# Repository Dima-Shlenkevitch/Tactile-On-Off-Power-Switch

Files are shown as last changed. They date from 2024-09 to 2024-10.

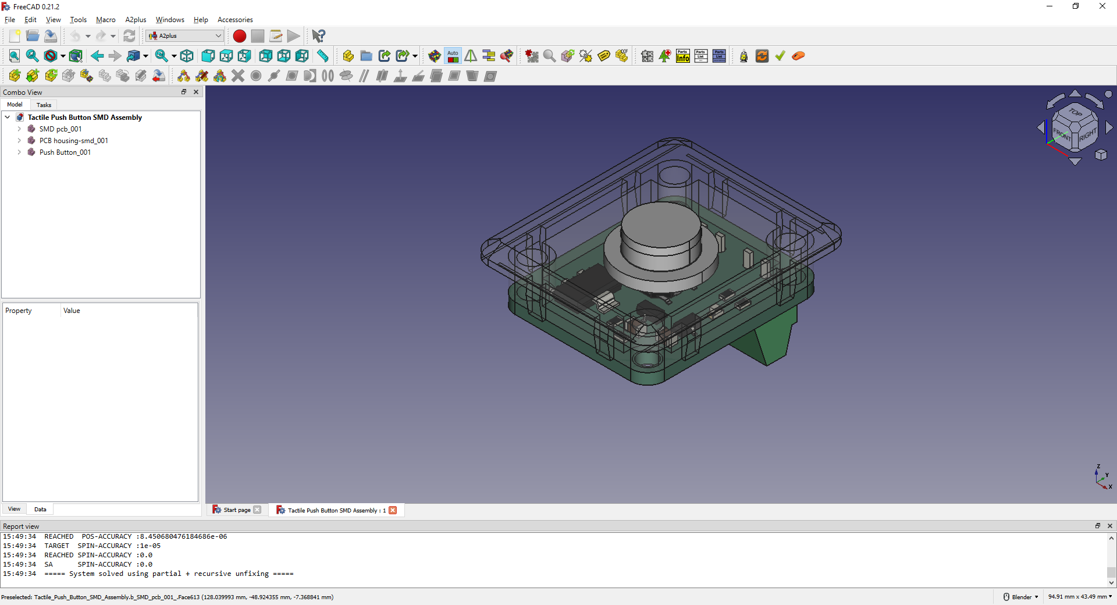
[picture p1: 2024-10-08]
Project Documentation/Step 2 - Design Phase/FreeCAD design - SMD.png

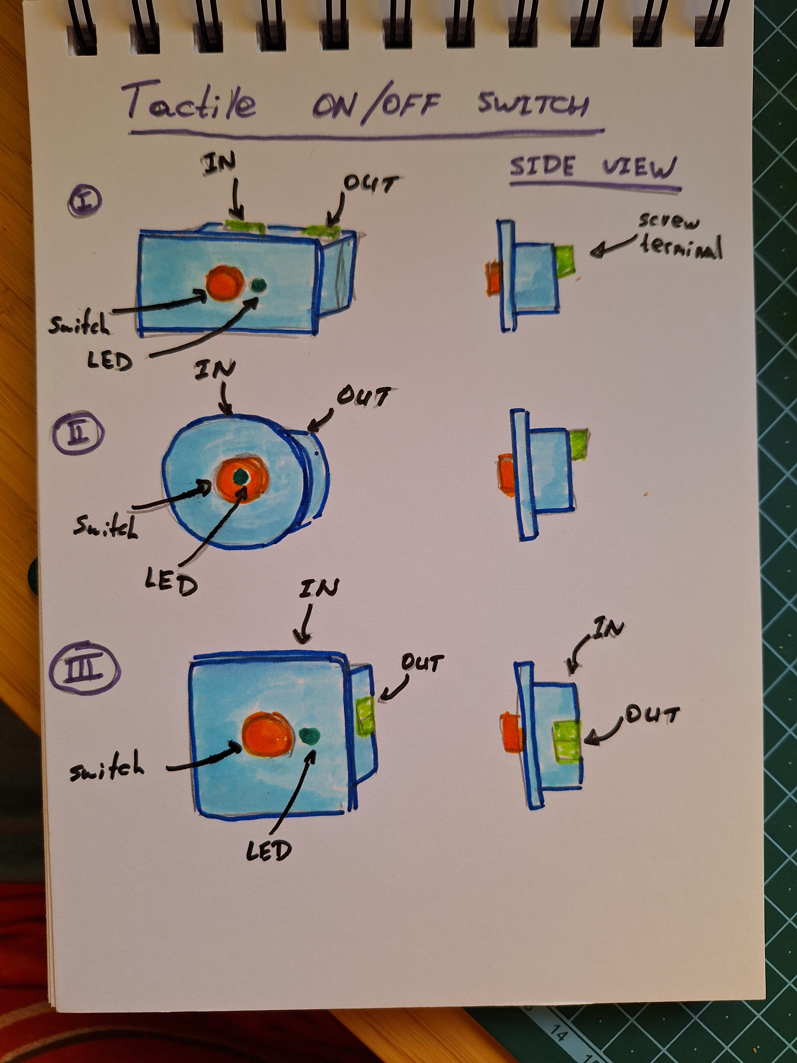
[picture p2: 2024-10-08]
Project Documentation/Step 1 - Conceptual Design/1. Hand Sketch/Concepts.jpg

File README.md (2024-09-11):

# Tactile ON / OFF Power Switch

## Project Overview
This project focuses on replacing a mechanical switch with a tactile push button and a latch circuit.

The project was inspired by an excellent video from Great Scott:
https://www.youtube.com/watch?v=y1ROEogHF7A

The main circuit remains similar to the reference design.

## Key features of this design include:
* Small footprint
* SMD components
* Mechanical enclosure for panel installation

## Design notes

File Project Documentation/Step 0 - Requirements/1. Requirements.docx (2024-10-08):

Requirements

Date: 1/9/24

Project Name: Tactile On/Off Switch Button

Responsible: D. Shlenkevitch

What the prototype should do?

The prototype replaces the on/Off mechanical switch with tactile button.

What are the must have features?

- The dimensions should be as small as possible
- The voltage input/output should be 0-12V
- The current should be up to 2A
- Screw terminals for input and output
- LED as visual indicator for power
- Mounting from the outer part of the panel

Nice to have features

- Ability to add different type of tactile switches
- Ability to mount from inner part of the panel

What are the limitations?

- Dimensions: Below 20 x 20 mm
- Price: Low price is needed, for mass production the BOM < 1$
- Specific components: N/A

Is any regulation compliance required?

- N/A

Are there any other requirements?

- N/A

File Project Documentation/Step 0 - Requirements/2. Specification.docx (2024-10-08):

Specification

Date: 1/9/24

Project Name: Tactile On/Off Switch Button

Responsible: D. Shlenkevitch

Electrical:

Input/Output Voltage: 0 – 12 V

Current: < 2 A

Input/Output: Screw Terminal

Power available indicator: Green LED

Mechanical:

Height: < 20 mm

Length: < 20 mm

Width: < 40 mm (Flexible)

Mounting side: panel outer side

Optional: PCB with mounting holes for mounting on inner side

Software:

N/A

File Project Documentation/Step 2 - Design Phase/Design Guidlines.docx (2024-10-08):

Moto: Don’t try to make the perfect prototype / product!

It is not possible! Nothing is perfect!

- Start project
- Init git
- Init github
- Capture main schematics
- Choose the components that you want

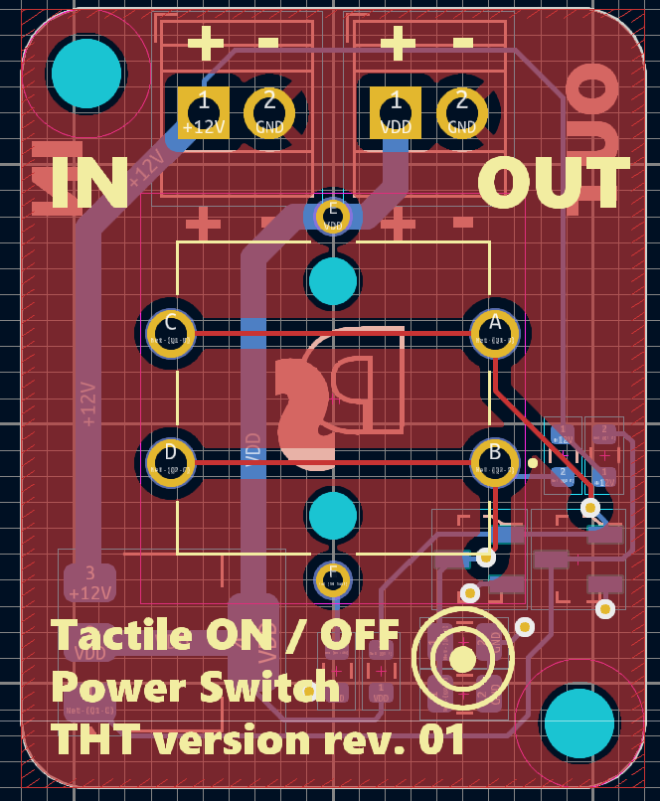
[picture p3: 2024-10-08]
Project Documentation/Step 2 - Design Phase/Electrical Design/Layout.PNG

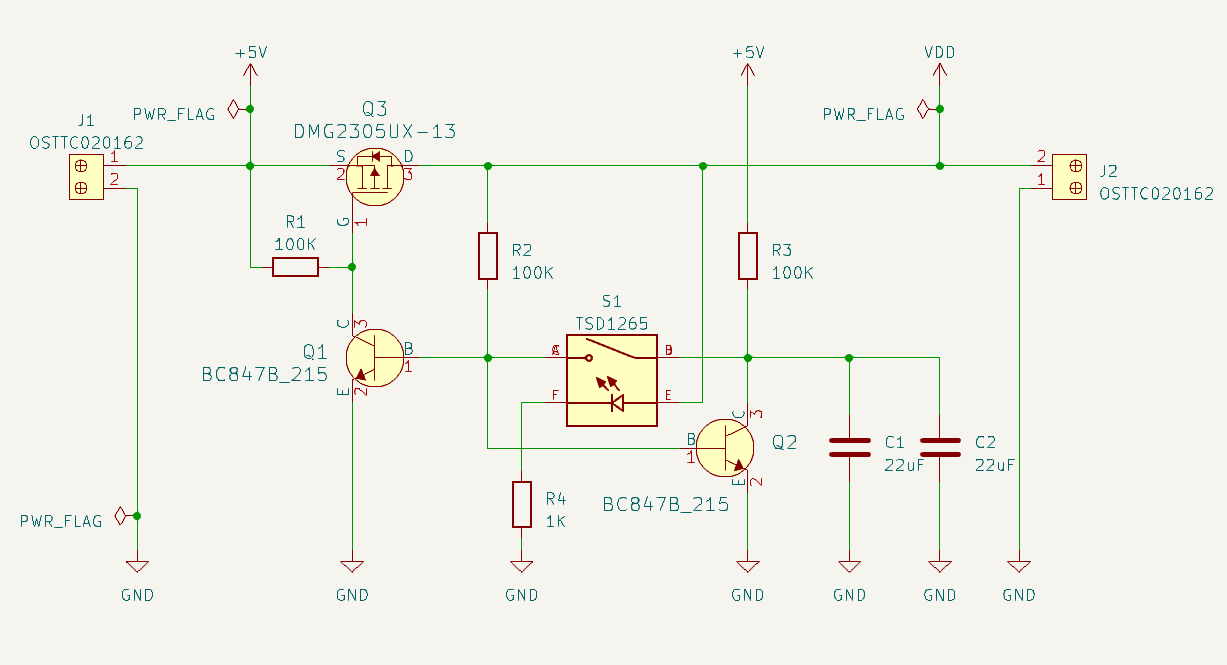
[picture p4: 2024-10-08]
Project Documentation/Step 2 - Design Phase/Electrical Design/Capture Initial Design.PNG

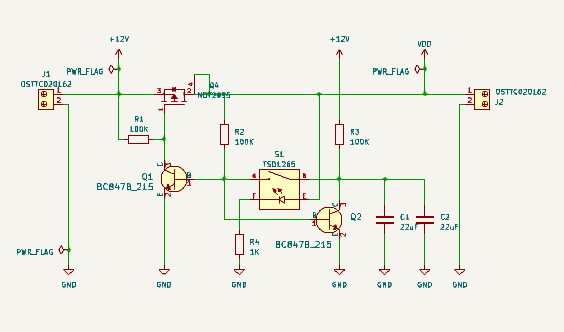
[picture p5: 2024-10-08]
Project Documentation/Step 2 - Design Phase/Electrical Design/Schematics.PNG

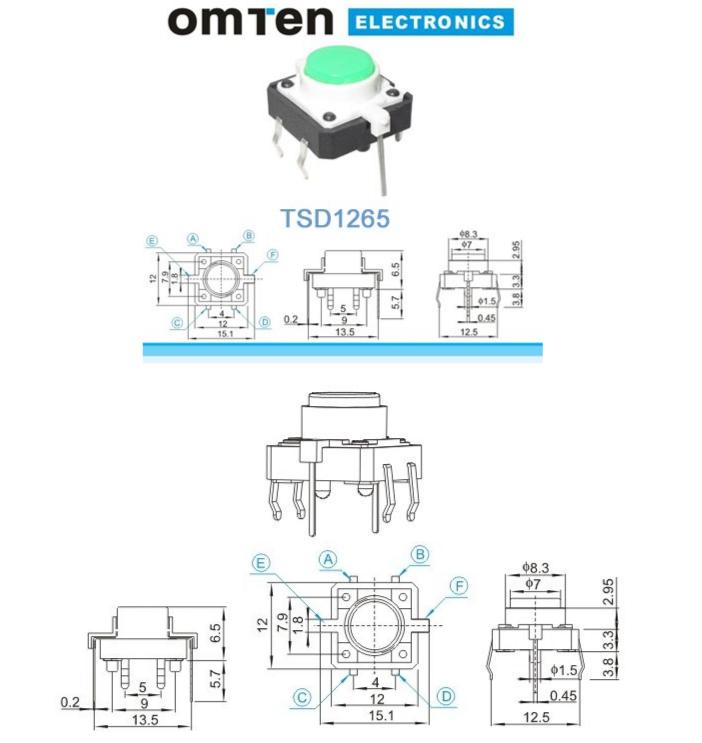
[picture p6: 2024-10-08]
Project Documentation/Step 2 - Design Phase/Electrical Design/Documents/push button spec 2.jpg

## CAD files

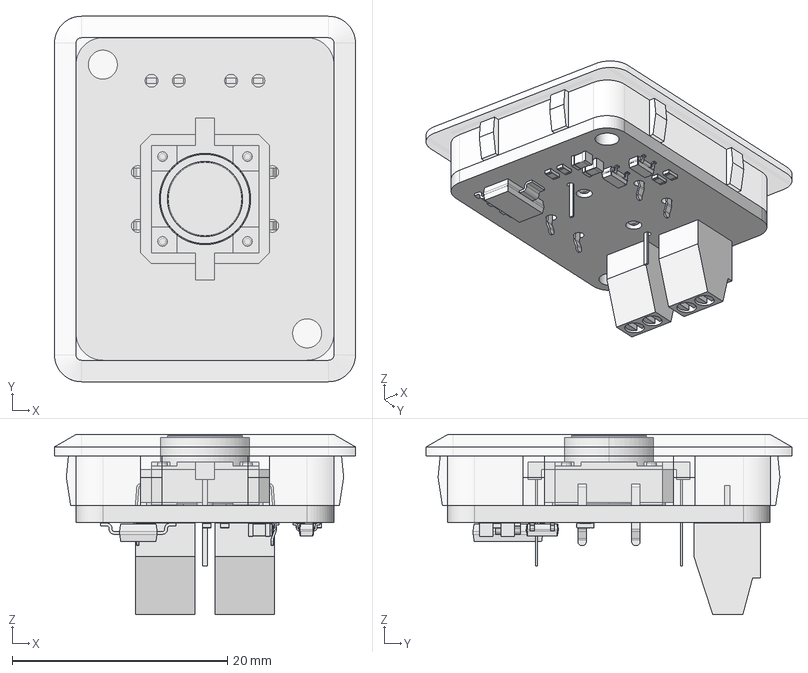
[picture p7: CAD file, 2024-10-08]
Project Documentation/Step 2 - Design Phase/Mechanical Design/Tactile Switch/Tactile Push Button Assembly.FCStd
28.0 x 34.0 x 16.7 mm
PCB housing_001
THT pcb_001

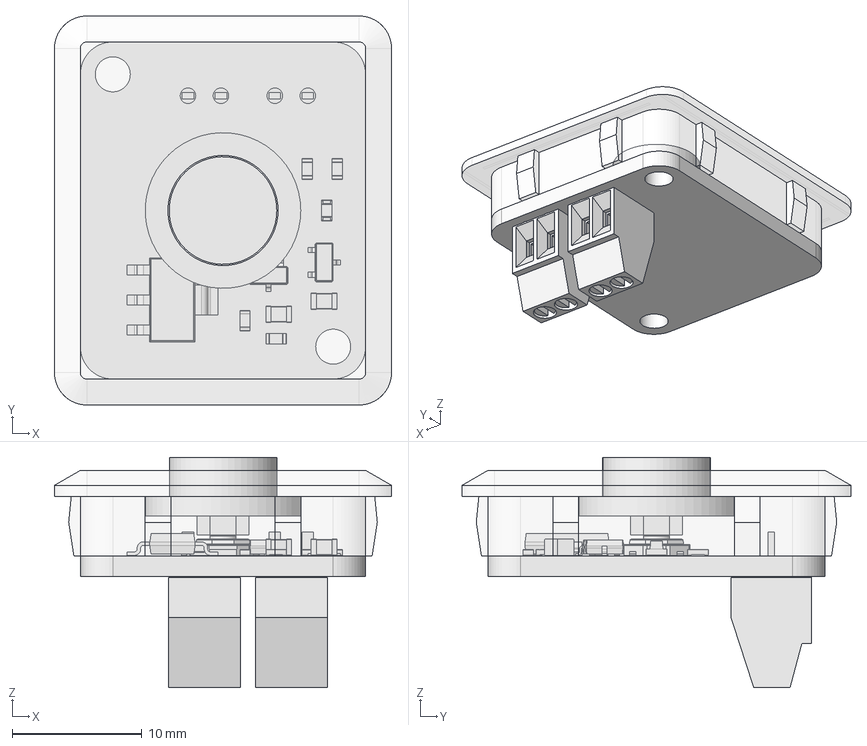
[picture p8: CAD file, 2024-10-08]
Project Documentation/Step 2 - Design Phase/Mechanical Design/Tactile Switch/Tactile Push Button SMD Assembly.FCStd
26.0 x 30.0 x 17.8 mm
SMD pcb_001
PCB housing-smd_001
Push Button_001

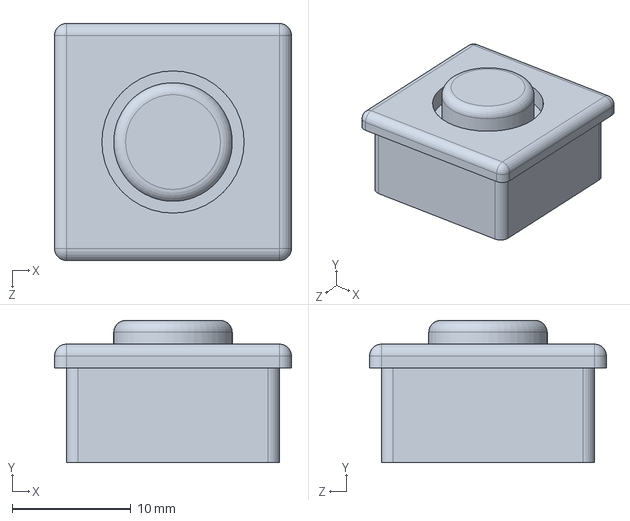
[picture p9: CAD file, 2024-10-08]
Project Documentation/Step 1 - Conceptual Design/2. Test Models/Concept 1 - Square.SLDPRT
20.0 x 12.0 x 20.0 mm

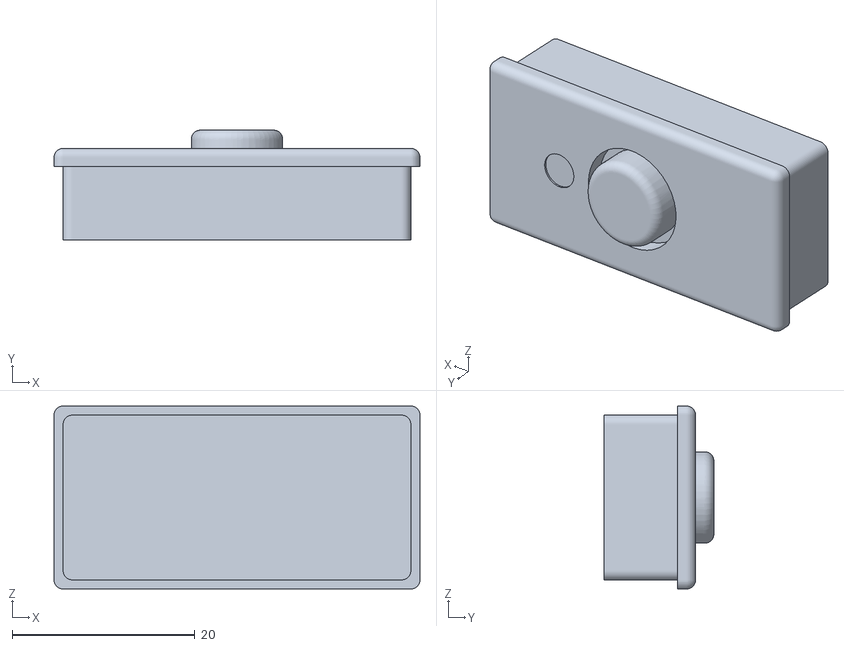
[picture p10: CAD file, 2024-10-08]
Project Documentation/Step 1 - Conceptual Design/3. 3D Printing/Concept 2 - Rectangle.STL
40.0 x 12.0 x 20.0

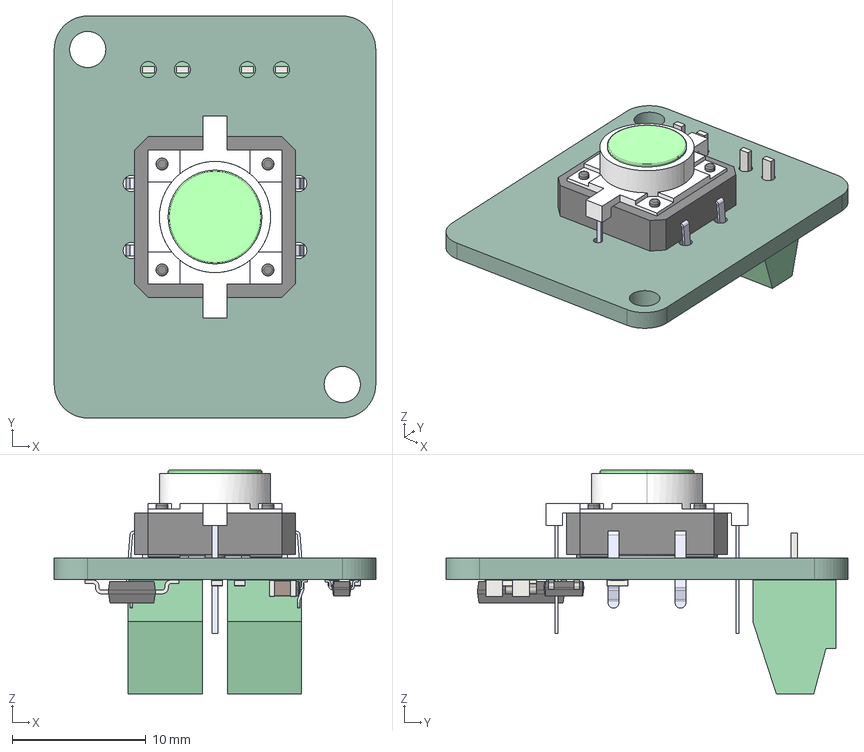
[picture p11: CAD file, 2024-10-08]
Project Documentation/Step 2 - Design Phase/Mechanical Design/Tactile Switch/PCB Models/Tactile Power Switch-THT.step
24.0 x 30.0 x 16.7 mm
TSD1265
C_0805_2012Metric x 2
R_0603_1608Metric x 4
SOT-23-3 x 2
TerminalBlock_Phoenix_MPT_05_2_254_1x02_P254mm_Horizontal x 2
SOT_223
Tactile Power Switch_PCB

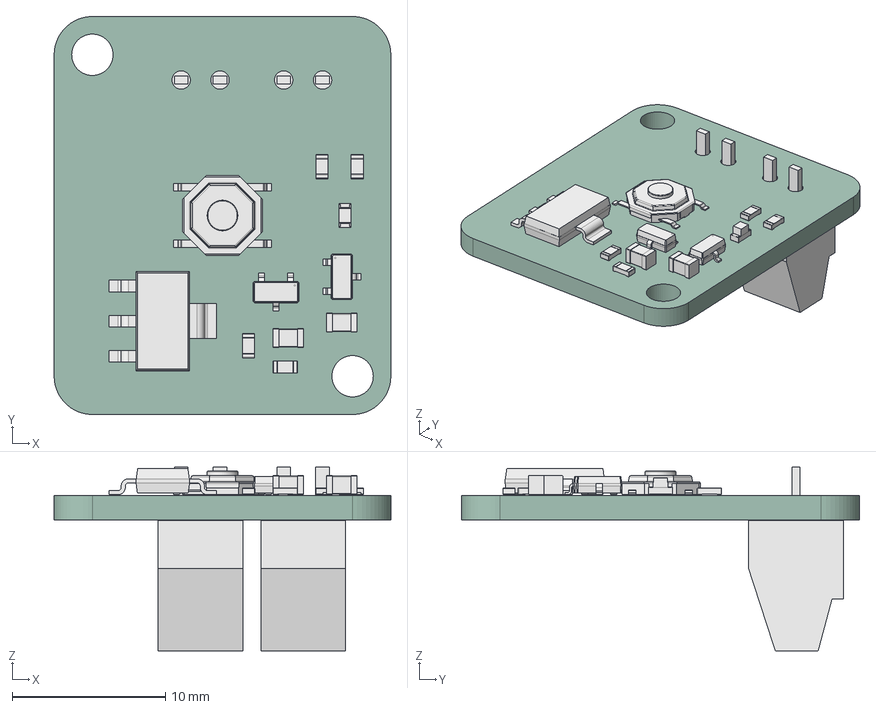
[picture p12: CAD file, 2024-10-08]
Project Documentation/Step 2 - Design Phase/Mechanical Design/Tactile Switch/SMD pcb.FCStd
22.0 x 26.0 x 12.0 mm
C_0805_2012Metric
R_0603_1608Metric
C_0805_2012Metric002
SOT-23-3
LED_0603_1608Metric
R_0603_1608Metric002
SW_SPST_TL3342
SOT_223
R_0603_1608Metric004
SOT-23-005
R_0603_1608Metric006
TerminalBlock_Phoenix_MPT_05_2_254_1x02_P254mm_Horizontal
TerminalBlock_Phoenix_MPT_05_2_254_1x02_P254mm_Horizontal001
Tactile Power Switch_PCB

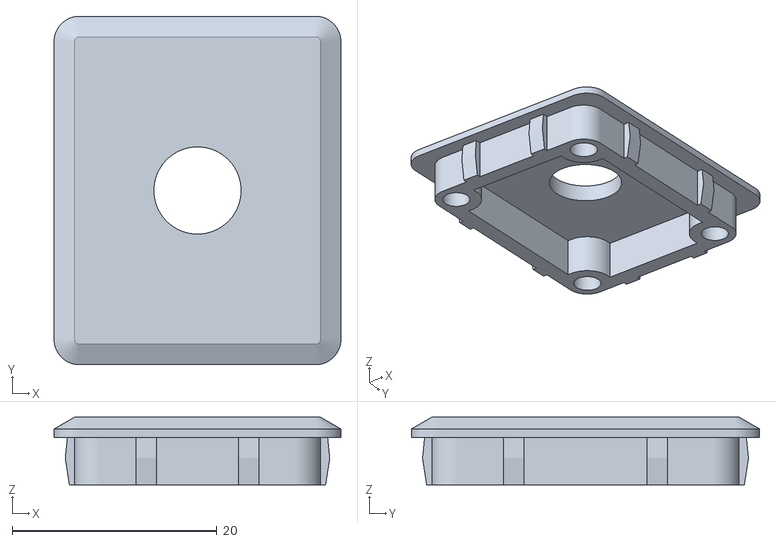
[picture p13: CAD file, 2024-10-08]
Project Documentation/Step 3 - Fabrication/Mechanics/3D Printing/PCB housing-THT.stl
28.0 x 34.0 x 6.60

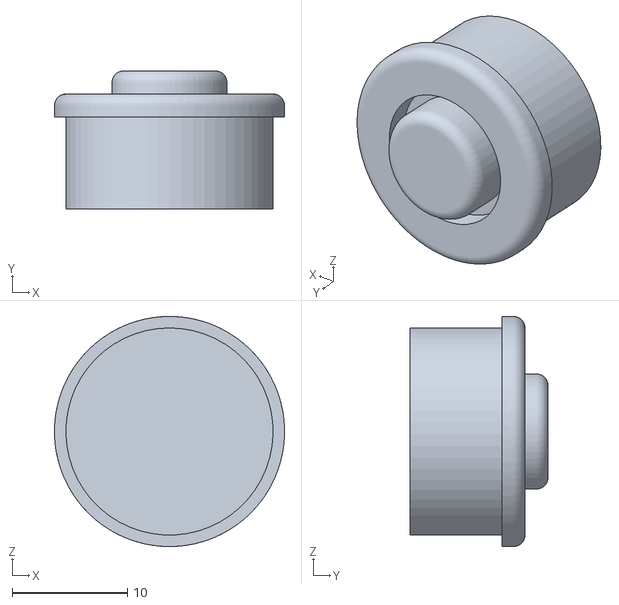
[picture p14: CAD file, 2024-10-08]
Project Documentation/Step 1 - Conceptual Design/3. 3D Printing/Concept 3 - Circle.STL
20.0 x 12.0 x 20.0

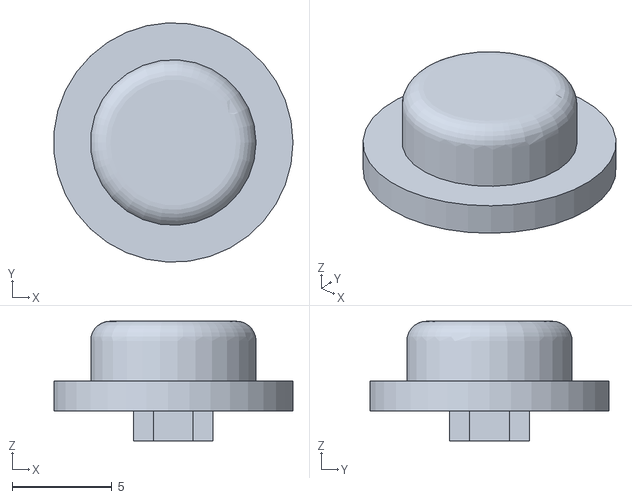
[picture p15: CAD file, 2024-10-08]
Project Documentation/Step 3 - Fabrication/Mechanics/3D Printing/Push Button-Body.stl
12.0 x 12.0 x 6.00

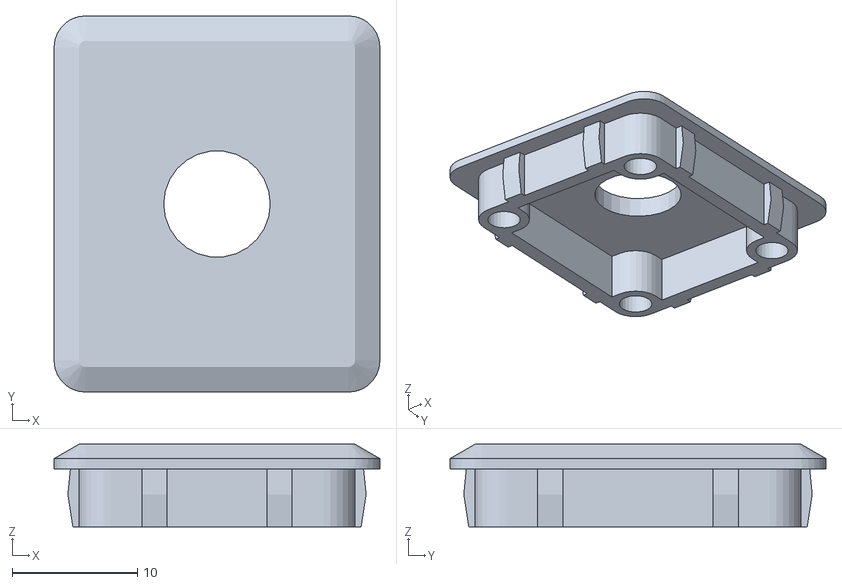
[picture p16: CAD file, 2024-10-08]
Project Documentation/Step 3 - Fabrication/Mechanics/3D Printing/PCB housing-smd-Body.stl
26.0 x 30.0 x 6.60

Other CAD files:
Project Documentation/Step 1 - Conceptual Design/2. Test Models/Concept 2 - Rectangle.SLDPRT
Project Documentation/Step 2 - Design Phase/Mechanical Design/Tactile Switch/PCB housing.FCStd
Project Documentation/Step 2 - Design Phase/Mechanical Design/Tactile Switch/PCB Models/Tactile Power Switch-SMD.step
Project Documentation/Step 1 - Conceptual Design/2. Test Models/Concept 3 - Circle.SLDPRT
Project Documentation/Step 1 - Conceptual Design/3. 3D Printing/Concept 1 - Square.STL
Project Documentation/Step 2 - Design Phase/Mechanical Design/Tactile Switch/THT pcb.FCStd
Project Documentation/Step 2 - Design Phase/Mechanical Design/Tactile Switch/PCB housing-smd.FCStd
Project Documentation/Step 2 - Design Phase/Mechanical Design/Tactile Switch/Push Button.FCStd
Project Documentation/Step 2 - Design Phase/Mechanical Design/Tactile Switch/Tacktile switch THT rev1.FCStd

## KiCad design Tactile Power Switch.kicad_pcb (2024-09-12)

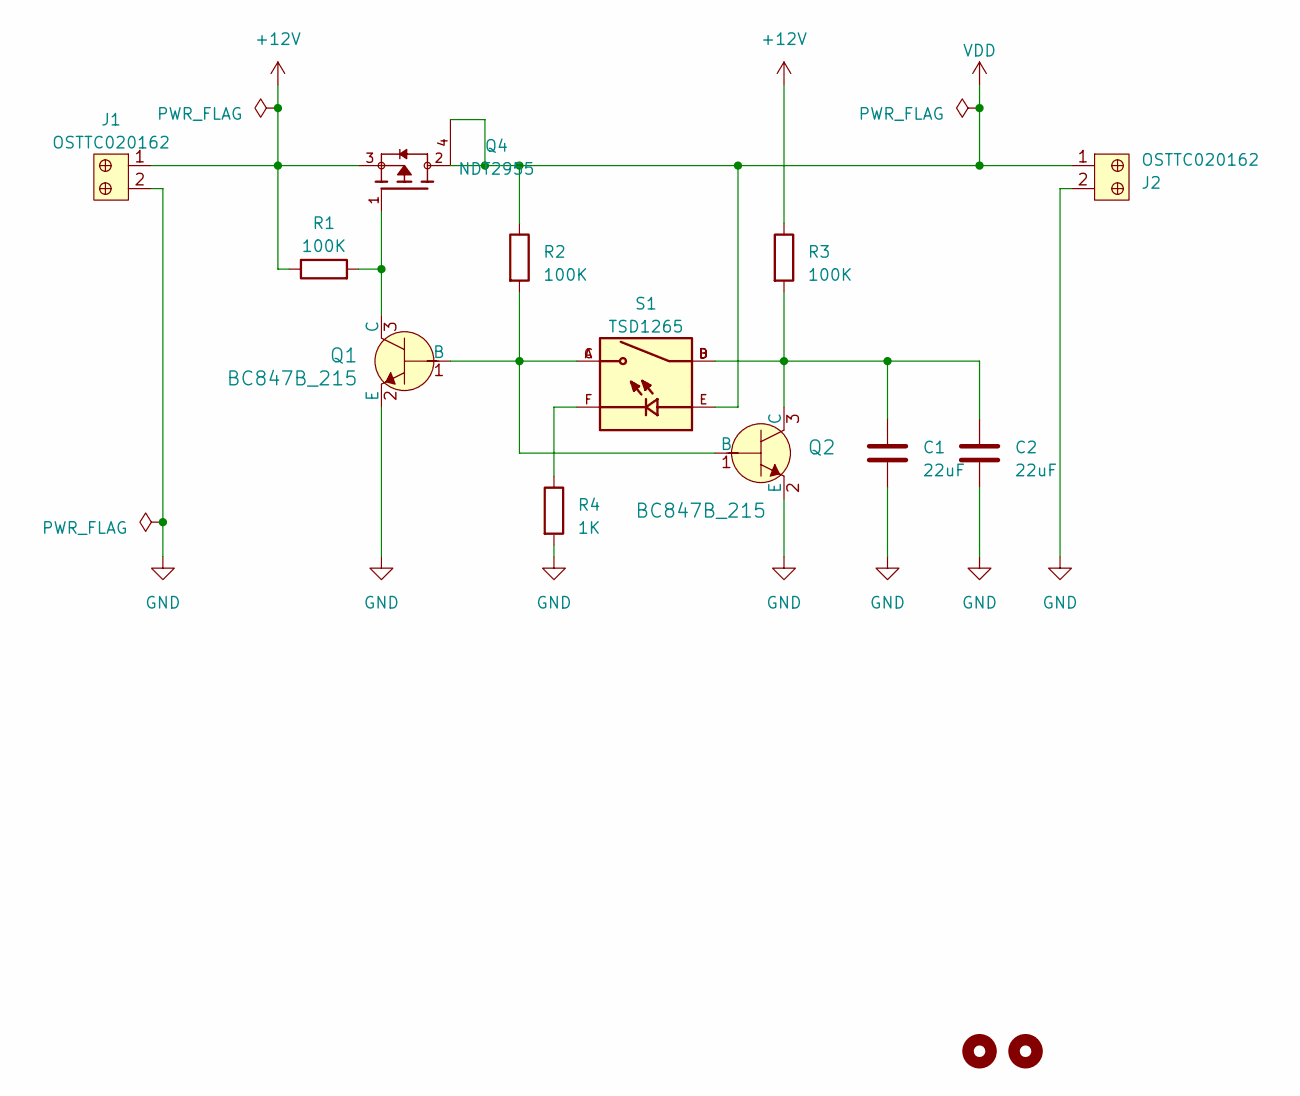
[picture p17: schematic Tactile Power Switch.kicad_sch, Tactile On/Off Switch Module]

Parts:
C1, C2: 22uF; C_0805_2012Metric
H1, H2: MountingHole; MountingHole_2.7mm_M2.5_ISO7380
J1, J2: OSTTC020162; TerminalBlock_Xinya_XY308-2.54-2P_1x02_P2.54mm_Horizontal; MPN OSTTC020162; Digi-Key_PN ED2600-ND
Q1, Q2: BC847B_215; SOT-23-3; MPN BC847B,215; Digi-Key_PN 1727-2921-1-ND
Q4: NDT2955; SOT-223
R1, R2, R3: 100K; R_0603_1608Metric
R4: 1K; R_0603_1608Metric
S1: TSD1265; SW_TSD1265; PARTREV N/A

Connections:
+12V: J1.1, Q4.3, R1.1, R3.1
GND: C1.2, C2.2, J1.2, J2.2, Q1.2 (E), Q2.2 (E), R4.2
unnamed: Q1.1 (B), Q2.1 (B), R2.2, S1.A, S1.C
unnamed: Q1.3 (C), Q4.1, R1.2
unnamed: C1.1, C2.1, Q2.3 (C), R3.2, S1.B, S1.D
unnamed: R4.1, S1.F
VDD: J2.1, Q4.2, Q4.4, R2.1, S1.E

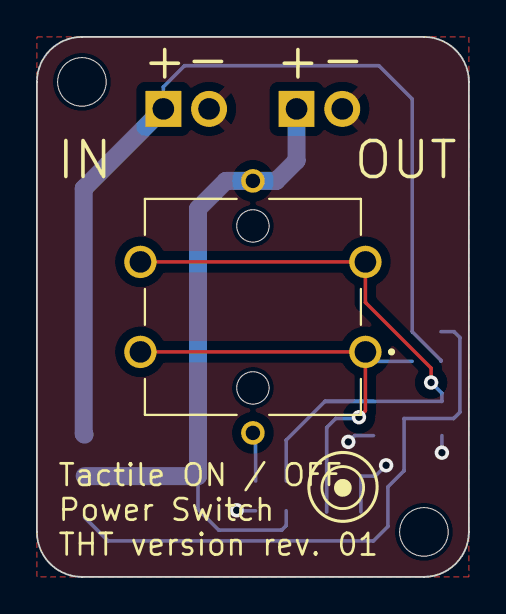
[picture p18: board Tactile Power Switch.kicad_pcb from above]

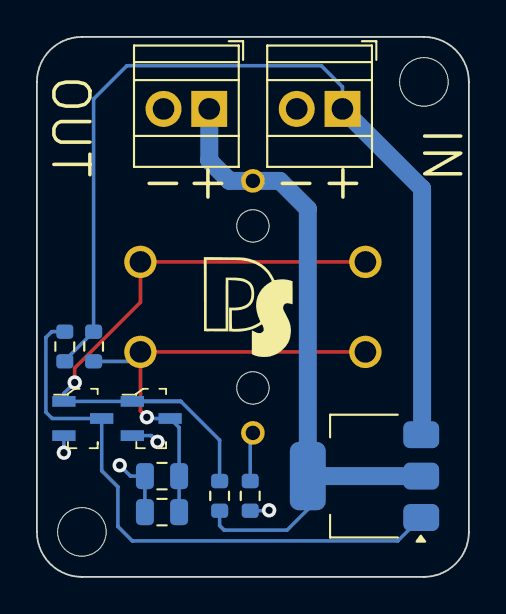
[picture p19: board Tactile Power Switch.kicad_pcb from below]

Board: 2 copper layers, 24.0 x 30.0 mm, 14 parts (11 on the bottom side), 7 nets.

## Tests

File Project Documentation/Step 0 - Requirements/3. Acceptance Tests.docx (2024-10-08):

Tests

Date: 1/9/24

Project Name: Tactile On/Off Switch Button

Responsible: D. Shlenkevitch

Electrical:

Max Voltage: 12V

Max Current: 2A

LED Test: Correct working

Mechanical:

Height (Actual):

Length (Actual):

Width (Actual):

Software:

N/A

Other:

N/A

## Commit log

2024-09-06 Project init
    [Tactile Power Switch.kicad_pcb, Tactile Power Switch.kicad_sch]
2024-09-06 Schmatics after final component selection
    [Tactile Power Switch.kicad_sch]
2024-09-06 Initial component placement
    [Tactile Power Switch.kicad_pcb]
2024-09-11 Placement Finished
    [Tactile Power Switch.kicad_pcb, Tactile Power Switch.kicad_sch]
2024-09-11 Palcement Change, Screw Terminal footfrint change to 2.54 inch and overall pcb outline optimization
    [Tactile Power Switch.kicad_pcb, Tactile Power Switch.kicad_sch]
2024-09-11 Initial Layout Finished - Next step to add silkscreen and final check
    [Tactile Power Switch.kicad_pcb]
2024-09-11 Silkscreen logos and description added
    [Tactile Power Switch.kicad_pcb]
2024-09-12 Terminal output connector configureation change
    [Tactile Power Switch.kicad_pcb, Tactile Power Switch.kicad_sch]
2024-09-12 MOSFET footprint update, Silkscreen update
    [Tactile Power Switch.kicad_pcb, Tactile Power Switch.kicad_sch]
2024-09-12 mfg files added
    [Tactile Power Switch-B_Cu.gbr, Tactile Power Switch-B_Mask.gbr, Tactile Power Switch-B_Paste.gbr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]
2024-09-18 CAD model generated
2024-10-08 Project Documentation added
    [Concept 1 - Square.SLDPRT, Concept 1 - Square.STL, Concept 2 - Rectangle.SLDPRT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]
